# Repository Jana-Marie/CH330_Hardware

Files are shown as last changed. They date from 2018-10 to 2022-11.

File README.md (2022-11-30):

# CH330_Hardware USB-UART Converter

I created this board because I wanted to play with the CH330N because it was supposed to be a crystal-less, <$0.35 USB UART converter in a SOIC-8 package. Since these chips were available from LCSC, I created a quick design and ordered both together.

As the IC is very small (other USB UART converters are packed in at least a QFN or SOIC-16), I didn't want the board to get much bigger. Accordingly, I developed this 10*10mm USB UART converter board with the CH330N and micro-USB. The assembly is quite fiddly, I suggest that you reflow the USB port and then solder the CH330N (and the LEDs) by hand. If you want to order these boards, I recommend you panelize them.

The CH330N enumerates as CH340 or CH341 and its transfer speed goes up to ~2Mb/s.

#### [More Info (Twitter Link)](https://twitter.com/_Jana_Marie/status/1057014341155872769)
#### [This project on Kitspace.org](https://kitspace.org/boards/github.com/jana-marie/ch330_hardware/)

### Images

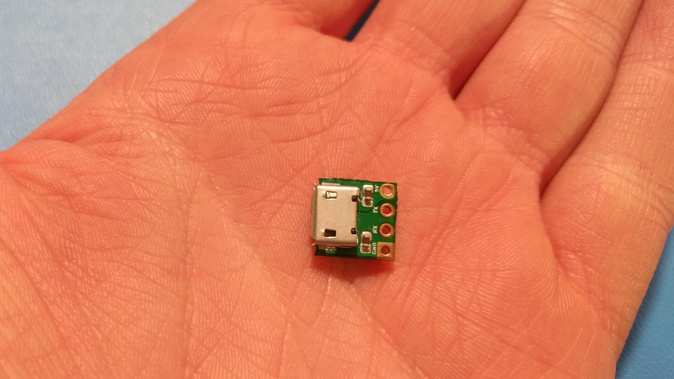
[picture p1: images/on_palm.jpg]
CH330 in the palm of a hand

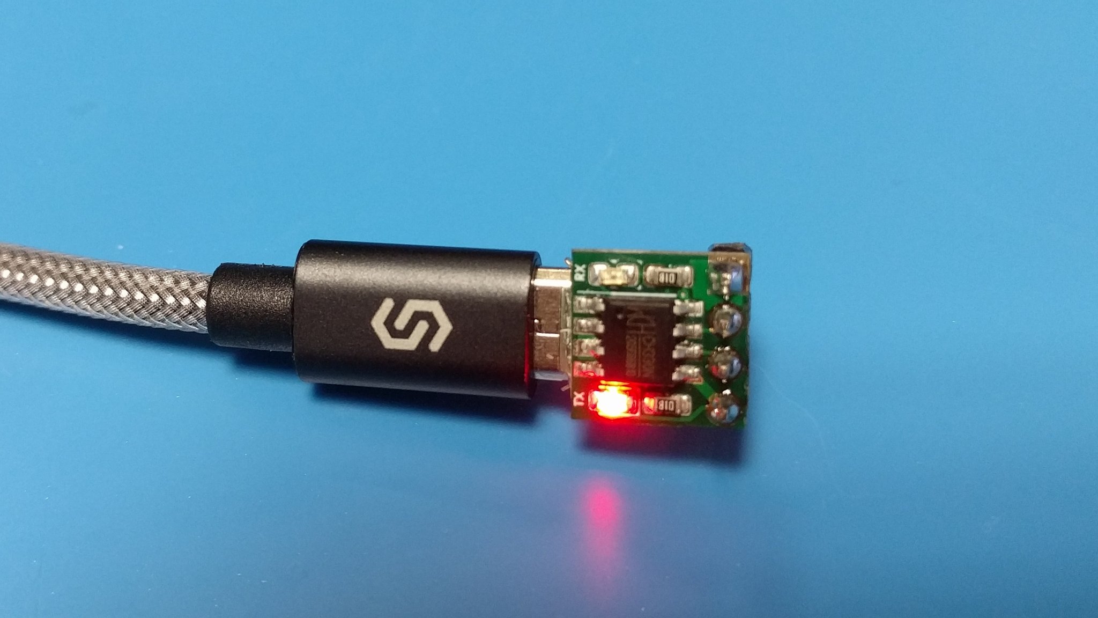
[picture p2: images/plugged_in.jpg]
CH330 plugged into USB

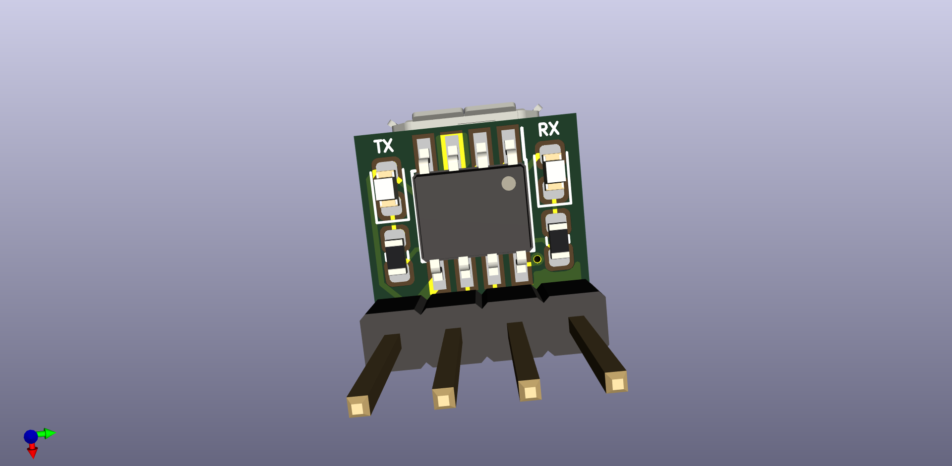
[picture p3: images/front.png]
Front render

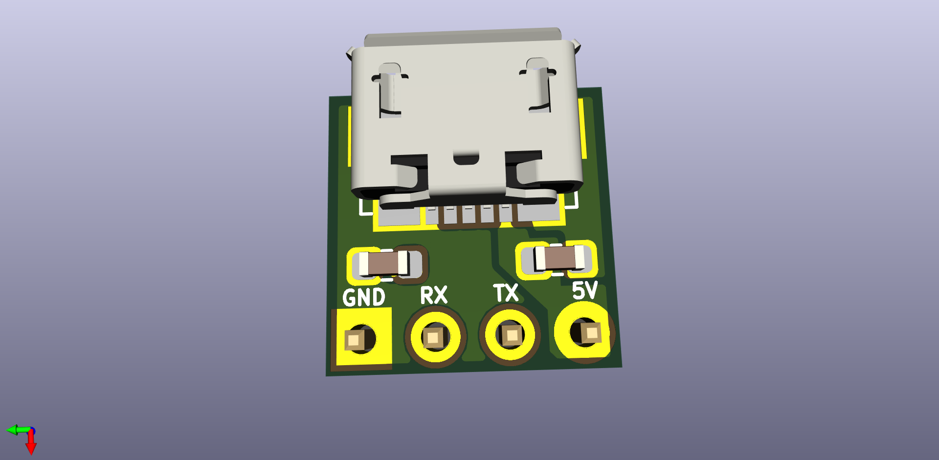
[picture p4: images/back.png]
Back render


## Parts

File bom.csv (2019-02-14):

References | Qty | Description | Manufacturer | MPN | Digikey | Mouser | RS | Newark | Farnell
C1,C2 | 2 | 0.1µF 0603 50V | AVX | 06035G104ZAT2A | 311-1344-1-ND | 603CC603KRX7R9BB104 | 1358345 | 96M1293 | 1288255
D1,D2 | 2 | LED 0603 | Everlight | 19-217/BHC-ZL1M2RY/3T | 160-1183-1-ND | 859LTSTC190GKT | 6910451 | 68Y1165 | 1652108
J1 | 1 | Micro USB |  |  | A97800CT-ND | 57119815681 | 6694645 | 73M8666 | 2751670
J2 | 1 | PinHeader 4 pin |  |  | WM2746-ND | 53822292041 | 6701333 | 26H2000 | 1360132
R1,R2 | 2 | 220R 0603 0.25W |  |  | P220BYDKR-ND |  | 8626833 | 85Y6302 | 2335874
U1 | 1 | CH330 SOIC-8 |  | https://lcsc.com/product-detail/USB_CH330N_C108996.html

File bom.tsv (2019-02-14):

References | Quantity | Description | PartNumber
C1,C2 | 2 | 0.1µF 0603 50V
D1,D2 | 2 | LED 0603
J1 | 1 | Micro USB
J2 | 1 | PinHeader
R1,R2 | 2 | 220R 0603 0.25W
U1 | 1 | CH330 SOIC-8

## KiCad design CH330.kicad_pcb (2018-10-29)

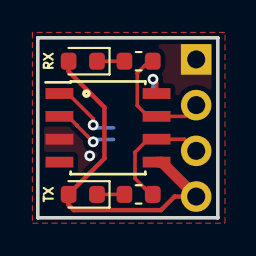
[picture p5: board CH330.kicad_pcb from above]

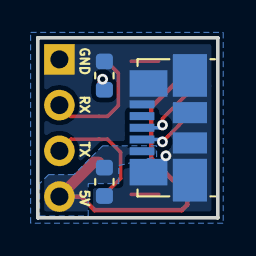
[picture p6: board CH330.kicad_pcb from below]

Board: 2 copper layers, 10.0 x 10.0 mm, 9 parts (3 on the bottom side), 9 nets.

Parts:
C1, C2: 100n; C_0603_1608Metric
D1, D2: LED; LED_0603_1608Metric
J1: USB_B_Micro; USB_Micro-B_Molex_47346-0001
J2: Conn_01x04_Female; PinHeader_1x04_P2.54mm_Vertica_WITHOUT_SILK
R1, R2: 220; R_0603_1608Metric
U1: CH330; SOIC-8_3.9x4.9mm_P1.27mm

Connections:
/D+: J1.3, U1.1
/D-: J1.2, U1.2
/RXD: J2.2, R2.2, U1.7
/TXD: J2.3, R1.2, U1.6
/V3: C2.1, U1.8
GND: C1.2, C2.2, J1.5, J1.6, J2.1, U1.3
unnamed: D1.1, R1.1
unnamed: D2.1, R2.1
VBUS: C1.1, D1.2, D2.2, J1.1, J2.4, U1.5

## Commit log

2018-10-29 added KiCAD files
    [CH330.kicad_pcb, CH330.sch]
2018-10-29 updated images
    [CH330-B.Cu.gbr, CH330-B.Mask.gbr, CH330-B.SilkS.gbr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]
2018-10-29 added gerber
    [CH330-B.Cu.gbr, CH330-B.Mask.gbr, CH330-B.SilkS.gbr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]
2018-10-29 updated PCB
    [CH330.kicad_pcb]
2019-02-14 moved bom
2019-02-14 updated bom
    [bom.tsv]
2019-02-14 added 1-click bom
    [bom.csv]
